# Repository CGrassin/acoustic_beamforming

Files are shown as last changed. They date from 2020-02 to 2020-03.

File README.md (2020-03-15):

# Acoustic Beamforming experiments

This repository contains all the ressources for my acoustic beamforming experiment using Arduino. This original article is here: http://charleslabs.fr/en/project-Acoustic+beamsteering+with+a+speaker+array

Various pieces of code/ressource are sorted by folder.

## Code_Pattern

This folder contains code to compute beamforming patterns.

The main script is beamforming_pattern_gen.py. Usage: `python3 beamforming_pattern_gen.py -h` (shows the help and options)

Sample output (`python3 beamforming_pattern_gen.py -f 1000 -a 10`):
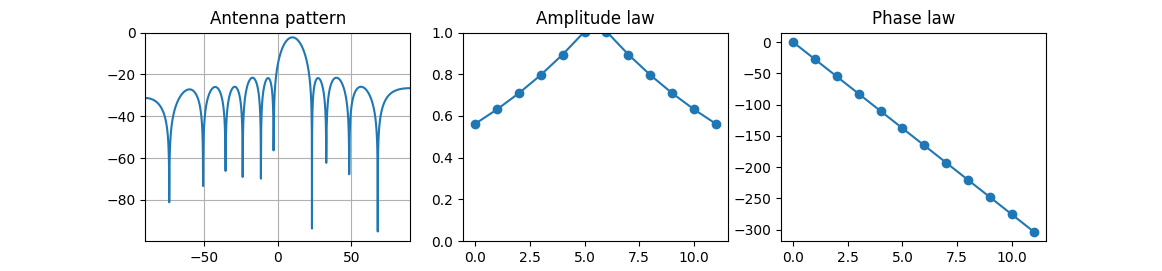
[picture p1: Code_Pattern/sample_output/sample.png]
Sample output for the beamforming pattern generator


Also included is a geogebra file for uniform amplitude law pattern simulation.

## Code_Arduino

This folder contains the code generator and the libraries to program the Arduino. It computes the timing to get the proper frequncy and phase between the elements. Usage:

```sh
python3 beamforming_code_gen.py -f 1000 -a 10
```

Output: Arduino code for the generation of a 1000Hz frequency wave, steered to +10 degrees.

Note: there is also a fully working, but deprecated Java version of this script that I created prior to the python version.

## Electronics

This folder contains the 12 channels signal generator PCB based around the FM62429 chips and the Arduino Nano microcontroller board. I used the open-source EDA KiCad.

## Experiments_Data

*WORK IN PROGRESS* This folder contains the data collected for each measurement, in CSV format. The first line of each CSV file contains all information to figure out it content.

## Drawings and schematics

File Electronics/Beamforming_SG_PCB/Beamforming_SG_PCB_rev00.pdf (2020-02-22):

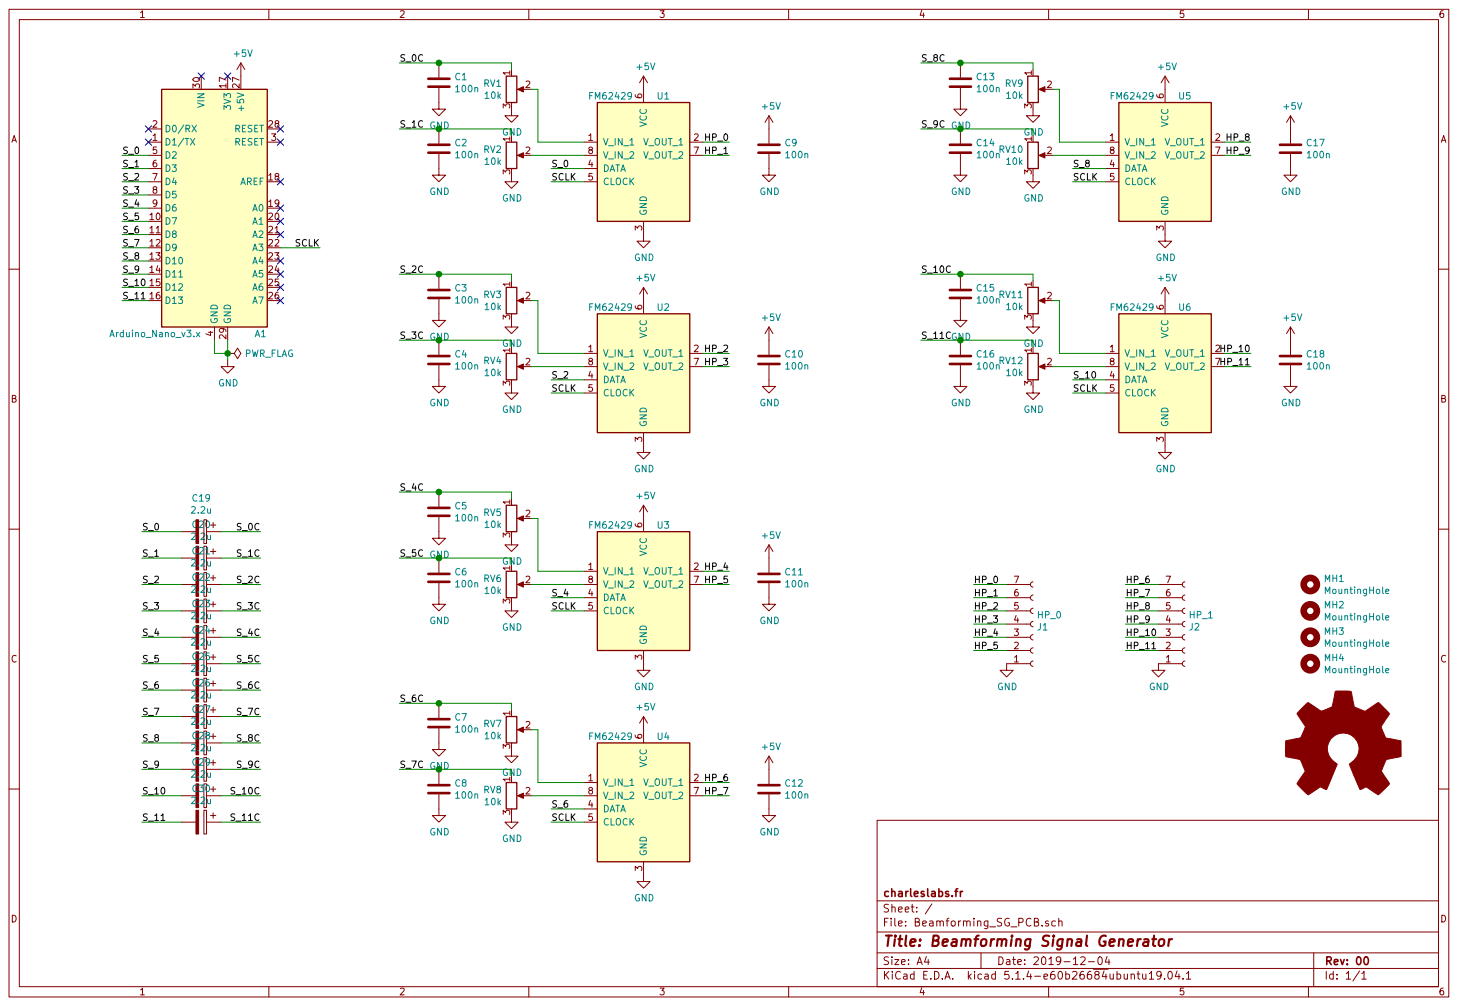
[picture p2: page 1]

Id: 1/1 Title: Beamforming Signal Generator

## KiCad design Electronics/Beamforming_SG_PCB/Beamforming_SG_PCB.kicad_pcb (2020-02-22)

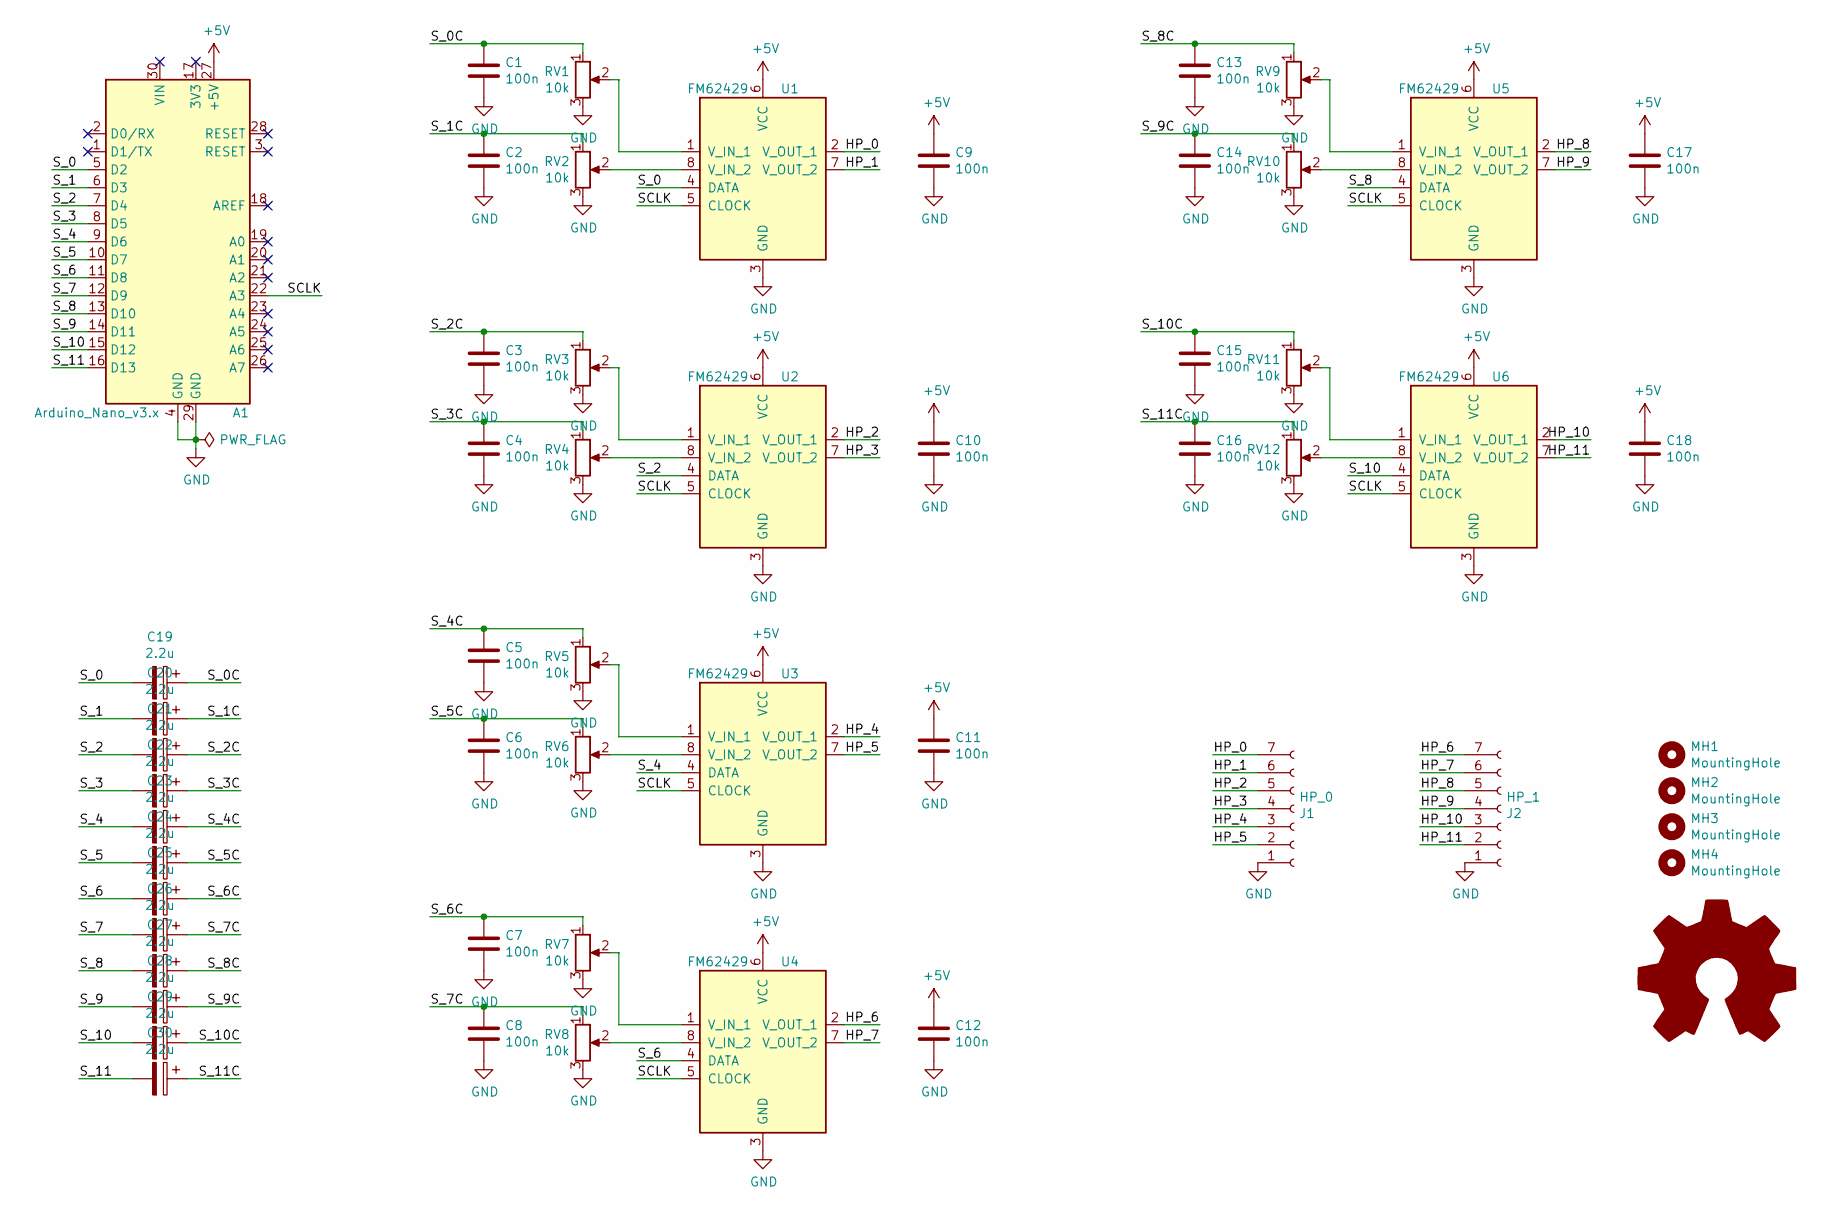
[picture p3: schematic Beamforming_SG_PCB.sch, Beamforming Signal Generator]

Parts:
A1: Arduino_Nano_v3.x; Arduino_Nano
C1, C2, C3, C4, C5, C6, C7, C8, C13, C14, C15, C16: 100n; C_0805_2012Metric
C9, C10, C11, C12, C17, C18: 100n; C_Disc_D4.3mm_W1.9mm_P5.00mm
C19, C20, C21, C22, C23, C24, C25, C26, C27, C28, C29, C30: 2.2u; C_0805_2012Metric
J1: HP_0; PinSocket_1x07_P2.54mm_Vertical
J2: HP_1; PinSocket_1x07_P2.54mm_Vertical
LOGO1: Logo_Open_Hardware_Large; OSHW-Symbol_8.9x8mm_SilkScreen
MH1, MH2, MH3, MH4: MountingHole; MountingHole_3.2mm_M3
RV1, RV2, RV3, RV4, RV5, RV6, RV7, RV8, RV9, RV10, RV11, RV12: 10k; Potentiometer_Bourns_3296W_Vertical
U1, U2, U3, U4, U5, U6: FM62429; DIP-8_W7.62mm

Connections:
+5V: A1.27 (+5V), C9.1, C10.1, C11.1, C12.1, C17.1, C18.1, U1.6 (VCC), U2.6 (VCC), U3.6 (VCC), U4.6 (VCC), U5.6 (VCC), U6.6 (VCC)
/HP_0: J1.7, U1.2 (V_OUT_1)
/HP_1: J1.6, U1.7 (V_OUT_2)
/HP_2: J1.5, U2.2 (V_OUT_1)
/HP_3: J1.4, U2.7 (V_OUT_2)
/HP_4: J1.3, U3.2 (V_OUT_1)
/HP_5: J1.2, U3.7 (V_OUT_2)
/HP_6: J2.7, U4.2 (V_OUT_1)
/HP_7: J2.6, U4.7 (V_OUT_2)
/HP_8: J2.5, U5.2 (V_OUT_1)
/HP_9: J2.4, U5.7 (V_OUT_2)
/HP_10: J2.3, U6.2 (V_OUT_1)
/HP_11: J2.2, U6.7 (V_OUT_2)
/SCLK: A1.22 (A3), U1.5 (CLOCK), U2.5 (CLOCK), U3.5 (CLOCK), U4.5 (CLOCK), U5.5 (CLOCK), U6.5 (CLOCK)
/S_0: A1.5 (D2), C19.2, U1.4 (DATA)
/S_0C: C1.1, C19.1, RV1.1
/S_1: A1.6 (D3), C20.2
/S_1C: C2.1, C20.1, RV2.1
/S_2: A1.7 (D4), C21.2, U2.4 (DATA)
/S_2C: C3.1, C21.1, RV3.1
/S_3: A1.8 (D5), C22.2
/S_3C: C4.1, C22.1, RV4.1
/S_4: A1.9 (D6), C23.2, U3.4 (DATA)
/S_4C: C5.1, C23.1, RV5.1
/S_5: A1.10 (D7), C24.2
/S_5C: C6.1, C24.1, RV6.1
/S_6: A1.11 (D8), C25.2, U4.4 (DATA)
/S_6C: C7.1, C25.1, RV7.1
/S_7: A1.12 (D9), C26.2
/S_7C: C8.1, C26.1, RV8.1
/S_8: A1.13 (D10), C27.2, U5.4 (DATA)
/S_8C: C13.1, C27.1, RV9.1
/S_9: A1.14 (D11), C28.2
/S_9C: C14.1, C28.1, RV10.1
/S_10: A1.15 (D12), C29.2, U6.4 (DATA)
/S_10C: C15.1, C29.1, RV11.1
/S_11: A1.16 (D13), C30.2
/S_11C: C16.1, C30.1, RV12.1
GND: A1.4 (GND), A1.29 (GND), C1.2, C2.2, C3.2, C4.2, C5.2, C6.2, C7.2, C8.2, C9.2, C10.2, C11.2, C12.2, C13.2, C14.2, C15.2, C16.2, C17.2, C18.2, J1.1, J2.1, RV1.3, RV2.3, RV3.3, RV4.3, RV5.3, RV6.3, RV7.3, RV8.3, RV9.3, RV10.3, RV11.3, RV12.3, U1.3 (GND), U2.3 (GND), U3.3 (GND), U4.3 (GND), U5.3 (GND), U6.3 (GND)
unnamed: RV1.2, U1.1 (V_IN_1)
unnamed: RV2.2, U1.8 (V_IN_2)
unnamed: RV3.2, U2.1 (V_IN_1)
unnamed: RV4.2, U2.8 (V_IN_2)
unnamed: RV5.2, U3.1 (V_IN_1)
unnamed: RV6.2, U3.8 (V_IN_2)
unnamed: RV7.2, U4.1 (V_IN_1)
unnamed: RV8.2, U4.8 (V_IN_2)
unnamed: RV9.2, U5.1 (V_IN_1)
unnamed: RV10.2, U5.8 (V_IN_2)
unnamed: RV11.2, U6.1 (V_IN_1)
unnamed: RV12.2, U6.8 (V_IN_2)

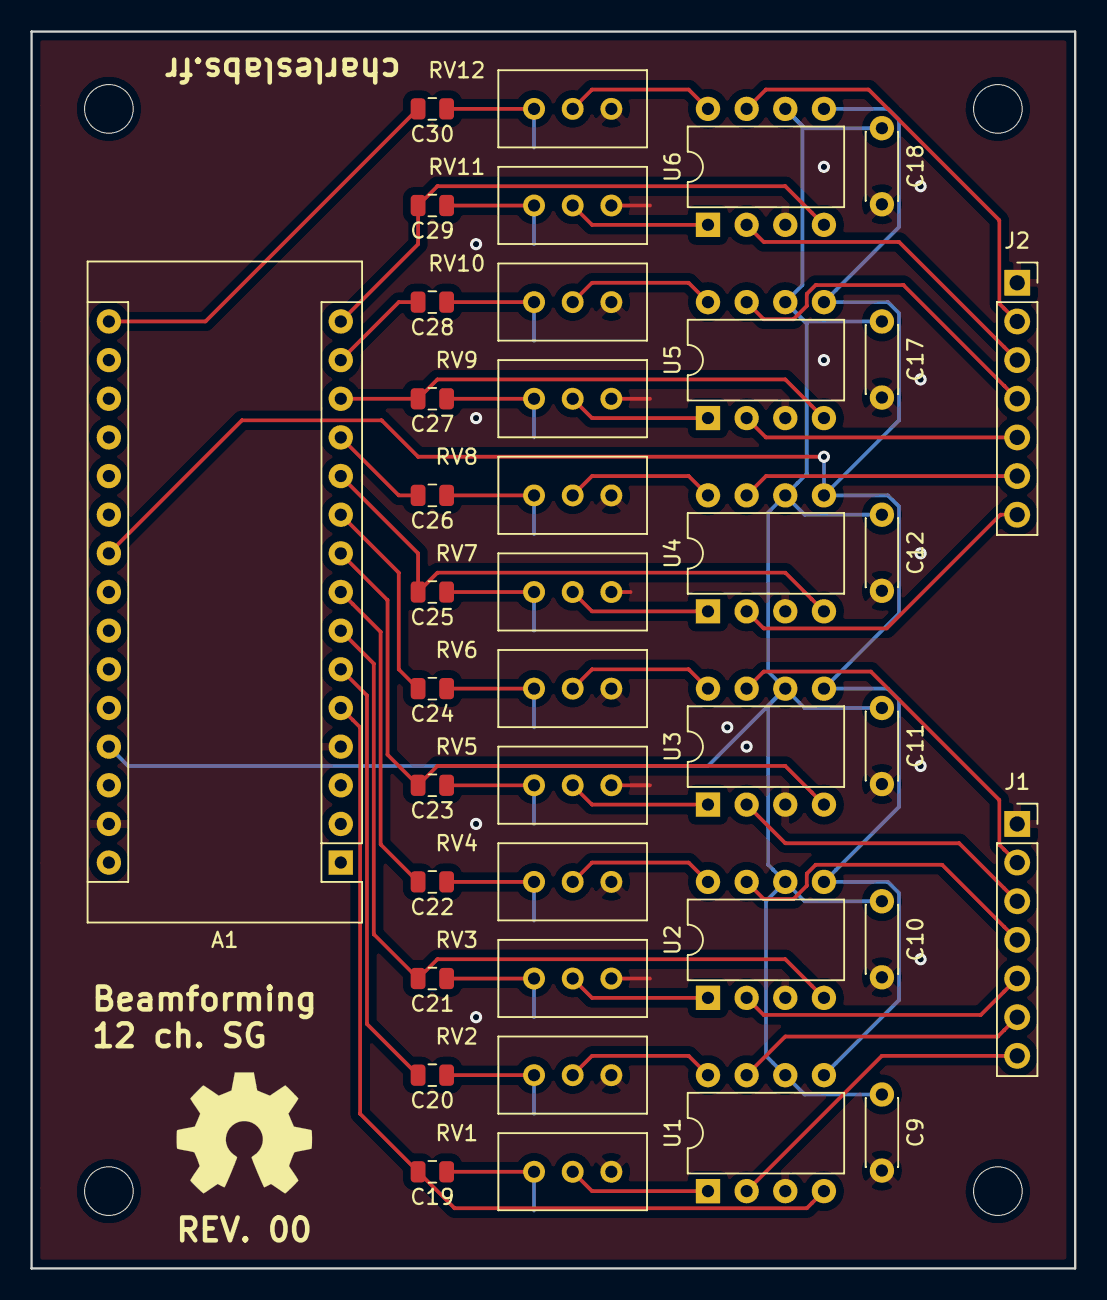
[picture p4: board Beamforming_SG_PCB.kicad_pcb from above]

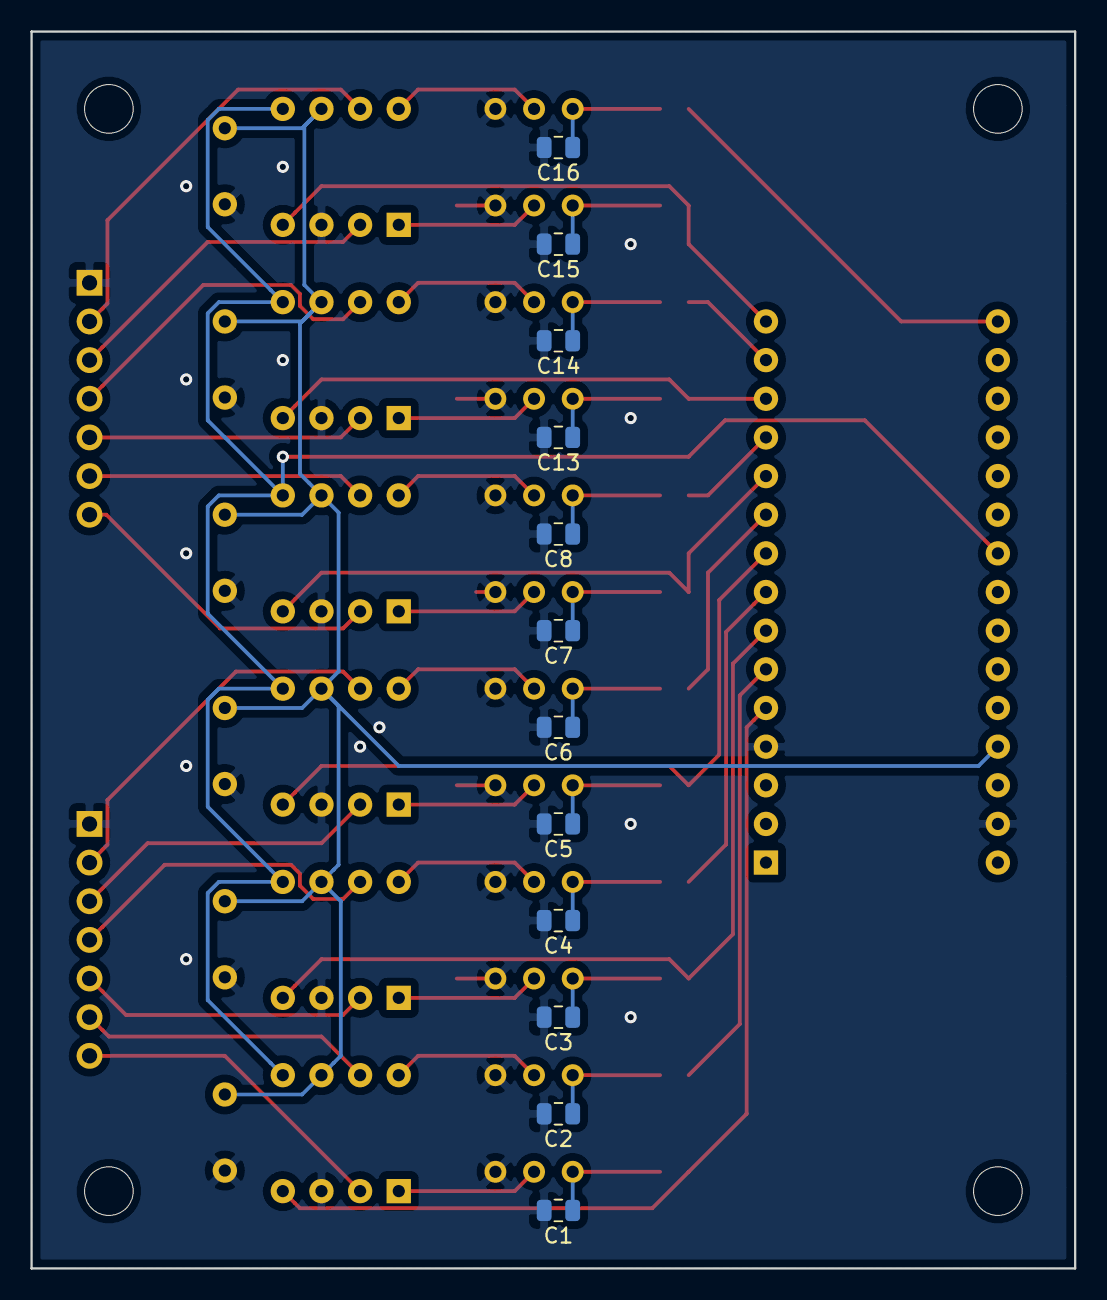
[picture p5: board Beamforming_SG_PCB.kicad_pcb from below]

Board: 2 copper layers, 68.6 x 81.3 mm, 56 parts (12 on the bottom side), 51 nets.

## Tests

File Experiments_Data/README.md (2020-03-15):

# Experiments

The experiments folders contains the Arduino signal generator used, the expected pattern according to these parameters and the actual measured pattern.
* Experiment 1: constant amplitude law, no phase law (steering angle = 0°),
* Experiment 2: constant amplitude law, phase law (steering angle = 30°),
* Experiment 3: linear log amplitude law, no phase law (steering angle = 0°).

The measurement were performed on my 12 speaker array with 15cm spacing between the elements.

Note: outliers were filtered out from raw data

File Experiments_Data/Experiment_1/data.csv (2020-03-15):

Angle (°) | Magnitude (dB)
10 | -56
15 | -58
20 | -56
25 | -54
30 | -56
35 | -57
40 | -56
45 | -56
50 | -55
55 | -53
57.5 | -55
60 | -54
62.5 | -53
65 | -52
67.5 | -53
70 | -50
72.5 | -50
75 | -48
77.5 | -46
80 | -45
85 | -47
87.5 | -46
90 | -47
92.5 | -48
95 | -47
97.5 | -46
100 | -45
102.5 | -46
105 | -48
107.5 | -47
110 | -48
112.5 | -52
115 | -54
120 | -53
122.5 | -55
125 | -54
127.5 | -54
130 | -54
135 | -57
140 | -51
145 | -57
155 | -54
160 | -57
165 | -58
170 | -57

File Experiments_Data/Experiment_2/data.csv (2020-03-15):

Angle (°) | Magnitude (dB)
10 | -56
20 | -57
30 | -59
40 | -58
50 | -57
60 | -55
70 | -59
80 | -55
85 | -56
90 | -55
92.5 | -53
95 | -54
97.5 | -52
100 | -53
102.5 | -51
105 | -50
110 | -49
112.5 | -48
115 | -47
117.5 | -48
120 | -49
122.5 | -47
125 | -48
127.5 | -48
130 | -49
132.5 | -49
135 | -51
137.5 | -52
140 | -53
142.5 | -54
145 | -54
150 | -55
155 | -56
160 | -59
165 | -60
170 | -59

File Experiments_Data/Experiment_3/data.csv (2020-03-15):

Angle (°) | Magnitude (dB)
10 | -68
15 | -64
20 | -66
30 | -65
35 | -66
40 | -65
45 | -67
55 | -65
57.5 | -64
60 | -63
62.5 | -62
65 | -61
67.5 | -61
70 | -63
72.5 | -60
75 | -60
77.5 | -61
80 | -58
82.5 | -58
85 | -57
90 | -58
92.5 | -57
95 | -58
100 | -57
102.5 | -60
105 | -62
107.5 | -59
110 | -61
112.5 | -61
115 | -62
117.5 | -61
120 | -63
125 | -62
127.5 | -63
130 | -62
135 | -64
140 | -65
150 | -68
155 | -66
160 | -65
170 | -68

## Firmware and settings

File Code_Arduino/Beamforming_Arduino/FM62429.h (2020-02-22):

/*
* This file controls the FM62429 chips in the CharlesLabs SG PCB (12 channel 
* with M62429 for software amplitude control).
* 
* Author: CGrassin (http://charleslabs.fr)
* License: MIT
*/

#ifndef FM62429_H
#define FM62429_H

#include "A328_PINS.h"

#define FM62429_CLK_PIN (A3)
#define FM62429_MIN_ATT (10) // Min attenuation = -3dB. This is a more reasonnable max volume
#define FM62429_MAX_ATT (40) // Max attenuation = -83dB. This is the max attenuation for audible sound.


/* Private : builds a FM62429 control word. */
uint16_t __buildWord(uint8_t attenuation, uint8_t channel, uint8_t individual){
  //if (attenuation > 83) attenuation = 83;
  uint16_t data_word = 0x00;

  // Cap
  if (attenuation > FM62429_MAX_ATT) attenuation = FM62429_MAX_ATT;
  if (attenuation < FM62429_MIN_ATT) attenuation = FM62429_MIN_ATT;

  // Build control word (11 bits)
  data_word |= (channel    << 0);        // Channel select: 0=ch1, 1=ch2
  data_word |= (individual << 1);        // Individual/both select: 0=both, 1=individual
  data_word |= ((21 - (attenuation / 4)) << 2);  // ATT1: coarse attenuator, steps of -4dB
  data_word |= ((3 -  (attenuation % 4)) << 7);  // ATT2: fine attenuator, steps of -1dB)
  data_word |= (0b11 << 9);              // 2 last bits must be 1

  return data_word;
}

/* Private: sets 6 channels of FM62429 chips.
* WARNING: DOES NOT WORK PROPERLY FOR ATT BETWEEN 0 and 2 dB!!!!
* MIN ATT = 3 dB
*/
void __setFM62429(uint8_t att1, uint8_t att2, uint8_t att3, uint8_t att4, uint8_t att5, uint8_t att6,uint8_t channel){
  uint16_t data_word1 = __buildWord(att1,channel,1);
  uint16_t data_word2 = __buildWord(att2,channel,1);
  uint16_t data_word3 = __buildWord(att3,channel,1);
  uint16_t data_word4 = __buildWord(att4,channel,1);
  uint16_t data_word5 = __buildWord(att5,channel,1);
  uint16_t data_word6 = __buildWord(att6,channel,1);

  // Send control word
  for (uint8_t i = 0; i < 11; i++) {
    delayMicroseconds (2);
    _PIN_WRITE (_D2 , 0);
    _PIN_WRITE (_D4 , 0);
    _PIN_WRITE (_D6 , 0);
    _PIN_WRITE (_D8 , 0);
    _PIN_WRITE (_D10, 0);
    _PIN_WRITE (_D12, 0);
    delayMicroseconds (2);
    digitalWrite (FM62429_CLK_PIN, 0);
    delayMicroseconds (2);
    _PIN_WRITE (_D2 , (data_word1 >> i) & 0x01);
    _PIN_WRITE (_D4 , (data_word2 >> i) & 0x01);
    _PIN_WRITE (_D6 , (data_word3 >> i) & 0x01);
    _PIN_WRITE (_D8 , (data_word4 >> i) & 0x01);
    _PIN_WRITE (_D10, (data_word5 >> i) & 0x01);
    _PIN_WRITE (_D12, (data_word6 >> i) & 0x01);
    delayMicroseconds (2);
    digitalWrite (FM62429_CLK_PIN, 1);
  }
  delayMicroseconds (2);
  _PIN_WRITE (_D2 , 1);
  _PIN_WRITE (_D4 , 1);
  _PIN_WRITE (_D6 , 1);
  _PIN_WRITE (_D8 , 1);
  _PIN_WRITE (_D10, 1);
  _PIN_WRITE (_D12, 1);
  delayMicroseconds (2);
  digitalWrite (FM62429_CLK_PIN, 0);
}

/* Public : sets all 12 channels attenuation. */
void initFM62429(uint8_t att1, uint8_t att2, uint8_t att3, uint8_t att4,  uint8_t att5,  uint8_t att6,
                 uint8_t att7, uint8_t att8, uint8_t att9, uint8_t att10, uint8_t att11, uint8_t att12){
  pinMode(FM62429_CLK_PIN, OUTPUT);
  __setFM62429(att1,att3,att5,att7,att9, att11,0);
  __setFM62429(att2,att4,att6,att8,att10,att12,1);
}

#endif
